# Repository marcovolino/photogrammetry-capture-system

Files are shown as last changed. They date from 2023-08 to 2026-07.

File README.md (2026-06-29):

# Photogrammetry Capture System

## Overview
This repository contains a set of documents that outline the developement of a 64-camera photogrammetry system for the capture of human subjects.

**Please see the [project website](https://marcovolino.github.io/photogrammetry-capture-system/) for full details.**

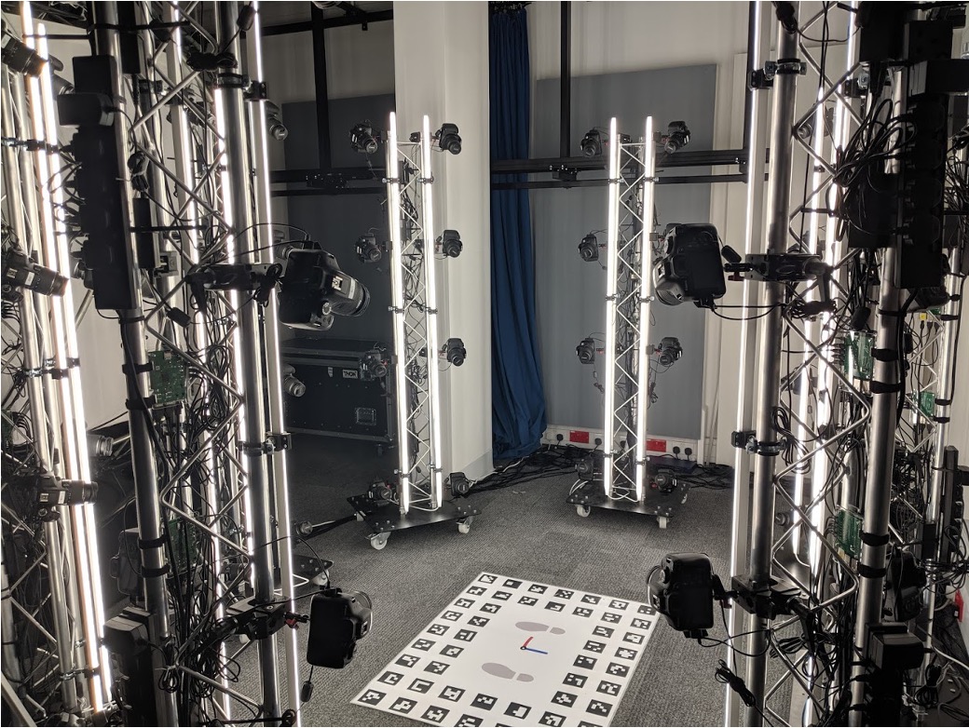
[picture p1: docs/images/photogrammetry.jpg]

<p style="text-align:center"><b>Figure 1:</b> Photogrammetry System</p>

If circumstances allow, the hardware design and software will be made open-source for others to recreate. For now, a description of the process can be found on the [project website](https://marcovolino.github.io/photogrammetry-capture-system/).

Any questions, [please get in touch](https://marcovolino.github.io/#contact).

## Updates
- 2023.08.11 - Repo/Site Created

## Documentation
- [System Overview](docs/system-overview.md)
- [Camera Synchronisation](docs/camera-sync.md)
- [Camera Control Software](docs/camera-control.md)
- [Control PC and Raspberry Pi Setup](docs/system-setup.md)
- [Floor Chart](docs/floor-chart.md)
- [Results](docs/results.md)

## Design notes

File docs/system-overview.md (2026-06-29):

---
layout: page
title: System Overview
---

This page gives a high-level overview of the capture system architecture.

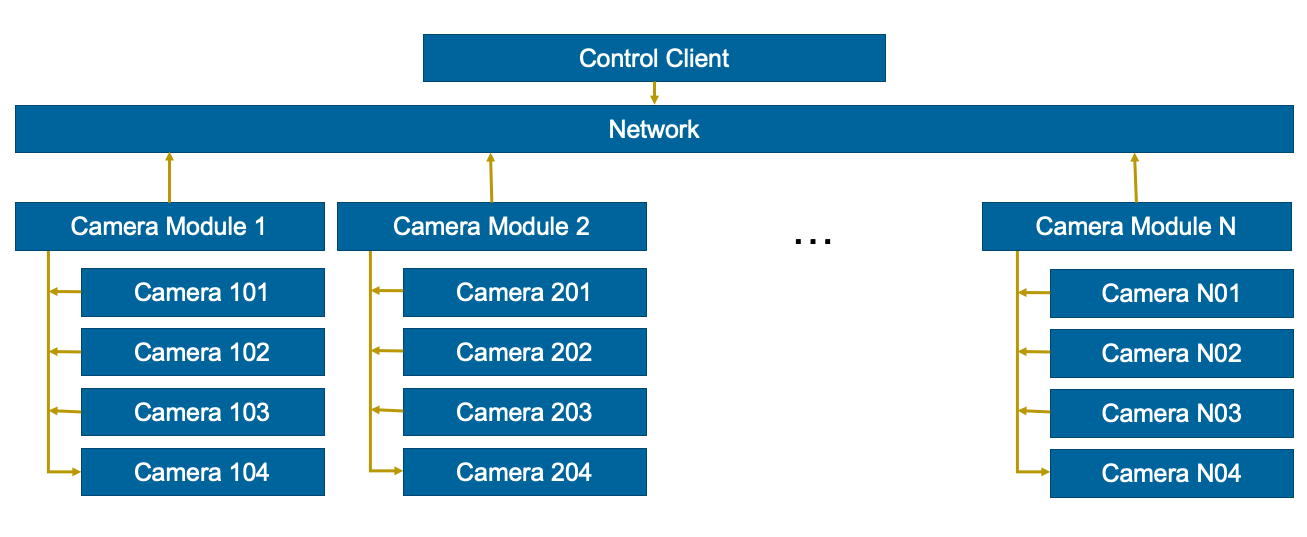
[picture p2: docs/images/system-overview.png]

<p style="text-align:center"><b>Figure 1:</b> System Overview</p>

The system consists of a central control PC and 16 camera modules connected over a local network. Each camera module is built around a [Raspberry Pi](https://www.raspberrypi.org/) and can support up to four DSLR cameras. Camera settings and image transfer are handled over USB, while autofocus and image capture is triggered through dedicated hardware so that all cameras fire at the same instant.

## Main Components

The control PC provides:

- A central operator interface for sending capture and configuration commands.
- A shared storage location for downloaded image data via FTP.
- A network time source so that Raspberry Pi modules can schedule captures from a common clock via NTP.

Each Raspberry Pi module provides:

- USB control for up to four DSLR cameras.
- A camera control server that listens for broadcast commands from the control PC.
- GPIO output for autofocus and shutter triggering through the custom trigger board.

Each DSLR camera provides:

- Image capture and local SD card storage.
- USB access for camera settings, card formatting, and image download.
- A 2.5 mm external trigger connection used by the synchronisation hardware.

## Capture Sequence

A typical capture follows this sequence:

1. The operator sends a command from the control PC.
2. The command is broadcast over UDP to the Raspberry Pi camera modules.
3. Each module schedules the capture using its local system clock.
4. At the trigger time, the module drives the GPIO trigger pin.
5. The custom trigger board closes the camera trigger circuit for each connected DSLR.
6. Captured images can then be downloaded from the cameras to the shared storage location.

The camera control software uses [libgphoto2](http://gphoto.org/) so that the control path is not tied to a single DSLR model, provided the camera is [supported by gphoto2](http://gphoto.org/proj/libgphoto2/support.php). The trigger hardware is camera-interface specific and was designed around DSLR bodies that expose focus and shutter control through a 2.5 mm remote trigger port.

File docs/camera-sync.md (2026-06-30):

---
layout: page
title:  Synchronisation
---

Photogrammetry systems designed to capture human subjects require precise shutter synchronisation so that all images represent the same instant. Even small timing differences can create reconstruction errors when the subject moves between frames.

This page describes the hardware-based synchronisation approach used by the system: a Raspberry Pi HAT that drives the external trigger inputs of multiple DSLR cameras.

## Camera Model

The [Canon EOS 1300D](https://www.canon.co.uk/for_home/product_finder/cameras/digital_slr/eos_1300d/) was selected because it offered a good balance of cost, resolution, external triggering support, and software control through libgphoto2.

The [camera control software](camera-control.md) is largely camera-model agnostic, provided the camera is supported by libgphoto2. The synchronisation hardware is more specific: it must match the camera's external trigger interface. Entry and mid-level Canon DSLR cameras commonly use a 2.5 mm jack for remote focus and shutter triggering.

## Software Trigger

Software triggering over USB was tested first. This approach was not precise enough for multi-camera human capture because it introduced variable delay between the first and last shutter event.

USB is still used for camera configuration and image transfer, but the capture signal is sent through the cameras' external trigger ports.

## Circuit Development and PCB Fabrication

The trigger board connects to the Raspberry Pi GPIO header and exposes multiple 2.5 mm trigger outputs for DSLR cameras. GPIO outputs from the Pi drive the trigger circuit, while opto-isolation helps separate the camera trigger lines from the Raspberry Pi electronics.

The following components were identified for building the circuit and sourced from <a target="_blank" href="https://uk.rs-online.com/web/">RS</a>.

<p style="text-align: center;"><b>Table 1: Component list with quantities per PCB and product links.</b></p>

| Component | Quantity per PCB | Link |
| --- | --- | --- |
| Diode (1N4148)	| 8 |<a target="_blank" href="https://uk.rs-online.com/web/p/switching-diodes/8431562">RS</a> |
| DIP Switch (SPST)| 1 |<a target="_blank" href="https://uk.rs-online.com/web/p/dip-sip-switches/8772154">RS</a> |
| GPIO Connector| 1| <a target="_blank" href="https://uk.rs-online.com/web/p/pcb-sockets/1731086">RS</a> |
| Headphone Jack (2.5mm) | 6 | <a target="_blank" href="https://uk.rs-online.com/web/p/products/5051407/">RS</a> |
| IC Dip Socket (8-way) | 1 |<a target="_blank" href="https://uk.rs-online.com/web/p/dil-sockets/6742435">RS</a>|
| Opto Isolator (CNY74-2)	| 1 | <a target="_blank" href="https://uk.rs-online.com/web/p/optocouplers/1451599/">RS</a>|
| Resistor (1k) | 2 |<a target="_blank" href="https://uk.rs-online.com/web/p/through-hole-resistors/7077666">RS</a>|

The circuit design was reproduced in <a target="_blank" href="https://www.kicad.org/">KiCad</a>, an open-source PCB design package.
KiCad was used to lay out the Raspberry Pi HAT form factor and route the trigger circuit. Some component footprints were not available in the default libraries, so custom footprints were created from the component datasheets.

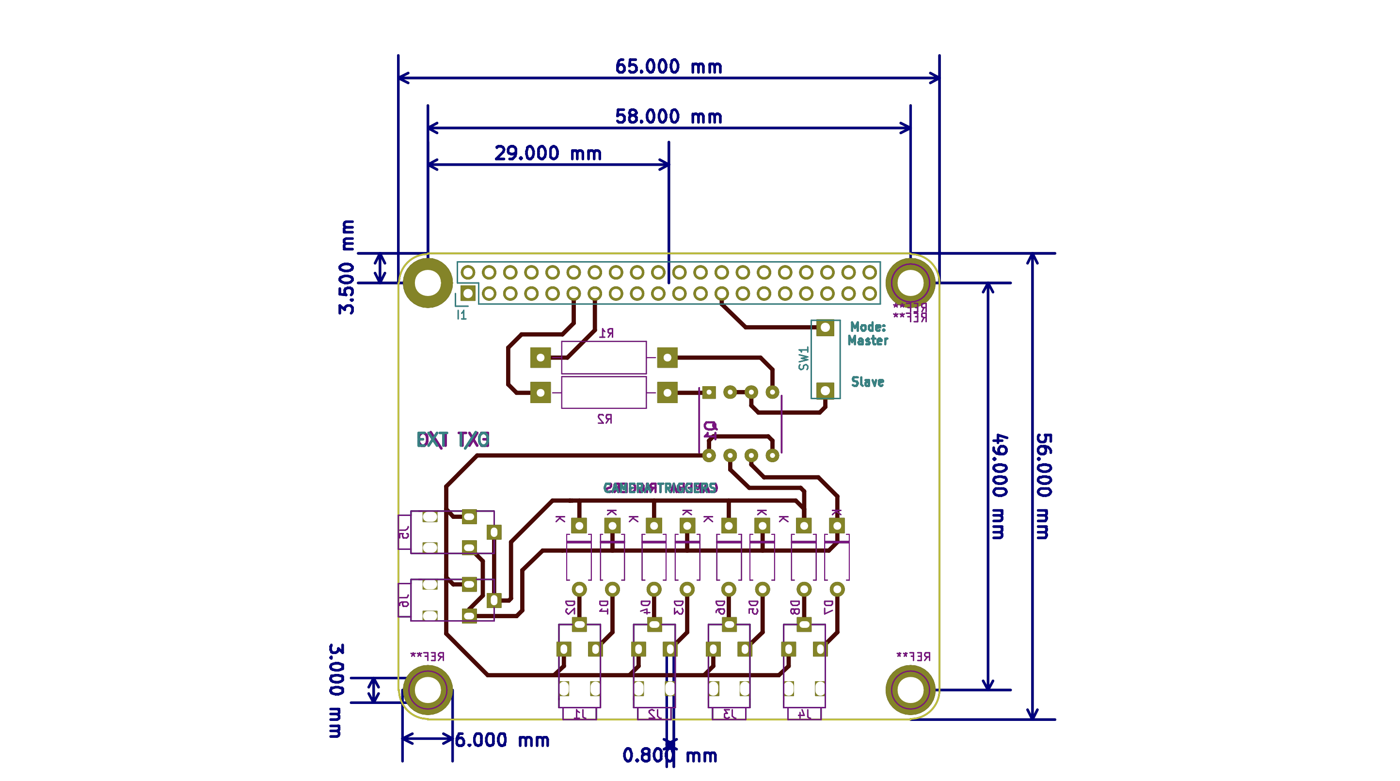
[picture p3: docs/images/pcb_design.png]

<p style="text-align: center;"><b>Figure 1:</b> PCB layout for the Raspberry Pi HAT trigger board.</p>

A prototype of the design was fabricated with the help of the University of Surrey's Electronics Lab, who used a UV etching process to create a PCB.
After confirming that the prototype circuit operated as expected, I began the process of fabricating 16 of the boards for the full system. 

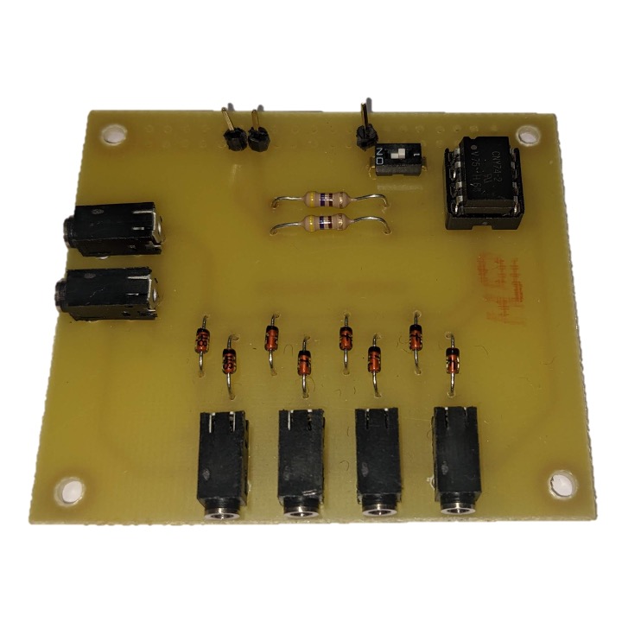
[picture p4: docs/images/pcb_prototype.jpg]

<p style="text-align: center;"><b>Figure 2:</b> Prototype PCB fabricated by the University of Surrey Electronics Lab using UV etching.</p>

The prototype fabrication process involved manually drilling component holes, which was not considered to be precise enough to ensure a high quality set of PCBs. 
For this reason, the manufacture of the final PCB boards was outsourced to a third party company.

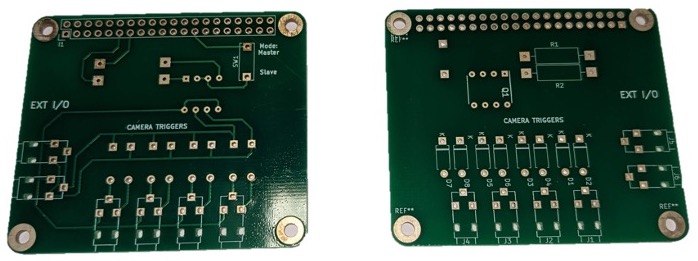
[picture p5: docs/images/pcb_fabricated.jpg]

<p style="text-align: center;"><b>Figure 3:</b> Fabricated PCB.</p>

Each PCB was then soldered together in the University of Surrey's Electronics Lab using the components listed previously.

## Synchronisation Tests

The synchronisation test captures the same moving event from multiple camera modules. If the trigger path is working correctly, the corresponding frames should show the event at the same point in time across cameras.
In figure 4, below, we see a croped image of an in-house synchronisation checker from 8 of the 16 camera modules. This demonstrates a high level of shutter synchronisation between independent cameras modules meaning a precise level of synchronisation, below 1/100th of a second, this is suitable for static human capture. 

This test is useful because it exercises the complete timing path:

- Network command broadcast from the control PC.
- Clock synchronisation between modules.
- Scheduled trigger timing on each Raspberry Pi.
- GPIO output through the trigger board.
- Camera response through the external trigger port.

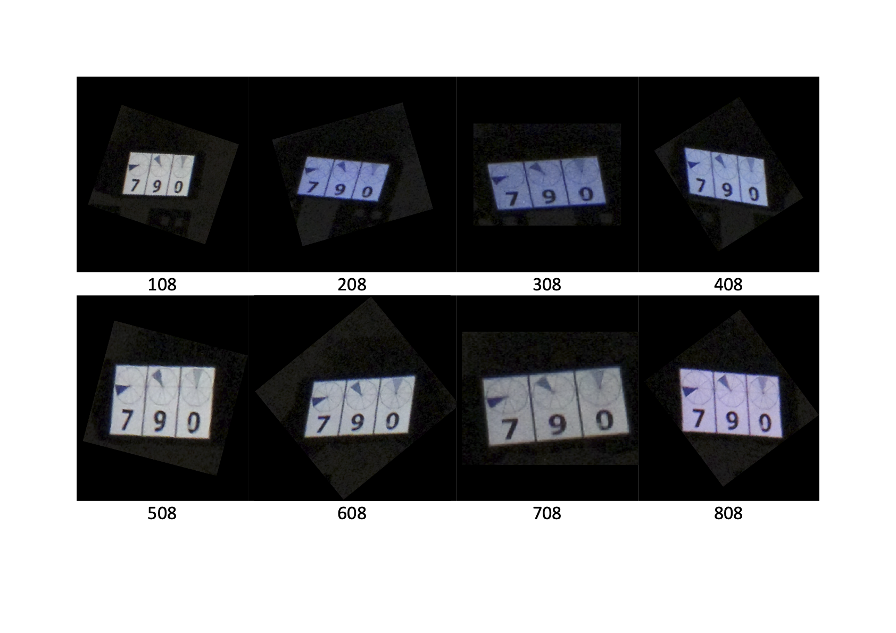
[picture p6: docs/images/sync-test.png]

<p style="text-align: center;"><b>Figure 4:</b> Images captured from different camera modules during a synchronisation test.</p>

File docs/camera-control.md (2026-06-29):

---
layout: page
title: Camera Control
---

The camera control software coordinates the central control PC and the Raspberry Pi camera modules. It provides a lightweight command interface for changing camera settings, triggering captures, downloading images, and managing camera modules.

The implementation is written in C++ and uses:

- [Boost.Asio](https://www.boost.org/doc/libs/release/doc/html/boost_asio.html) for UDP networking.
- [libgphoto2](http://gphoto.org/) for DSLR camera discovery, configuration, capture, download, and file deletion.
- [wiringPi](http://wiringpi.com/) for Raspberry Pi GPIO access.

## Architecture

The software is split into two applications:

- `CameraControlClient` runs on the control PC.
- `CameraControlServer` runs on each Raspberry Pi camera module.

The client sends commands to the modules using UDP broadcast. This keeps the control path simple: every active module receives the same command at the same time, and each module applies it to the cameras connected locally.

## Client Application

The client is an interactive command-line tool. It reads a JSON configuration file containing the broadcast address, UDP port, download directory, and optional host list for hard shutdown or reboot commands.

Example configuration:

```json
{
  "broadcast-address": "192.168.0.255",
  "port": 2000,
  "download": "/net_home/data",
  "pssh-hosts": "192.168.0.101 192.168.0.102"
}
```

The client maps single-key input to camera commands. Some commands prompt for a value, such as ISO, aperture, or shutter speed. Capture commands generate a future timestamp, allowing each camera module to trigger from its synchronized local clock.

## Server Application

The server listens for UDP commands on the configured port. When a command is received, it is parsed as either:

- `command`
- `command:value`

The server then applies the command to the local camera controller. Supported operations include:

- Detect connected cameras.
- Set ISO, aperture, and shutter speed.
- Trigger capture using GPIO.
- Enable or disable autofocus through GPIO.
- Download images to the configured destination.
- Format camera SD cards by deleting stored files.
- Shutdown or reboot the Raspberry Pi.

## Camera Discovery and Control

Each Raspberry Pi module uses libgphoto2 to detect cameras connected over USB. Detected cameras are opened, configured to store captures on their memory cards, and wrapped by the local camera controller.

Camera settings are applied using gphoto2 configuration keys:

- `iso`
- `aperture`
- `shutterspeed`

The software currently exposes a fixed set of accepted values for ISO, aperture, and shutter speed. These values should match the options supported by the selected camera model.

## Hardware Triggering

Although libgphoto2 can trigger image capture over USB, this was not accurate enough for synchronised multi-camera capture. The production capture path uses GPIO instead:

- One GPIO pin controls autofocus.
- One GPIO pin controls shutter trigger.
- The custom Raspberry Pi trigger board converts the GPIO output into the external trigger signal expected by the cameras.

This keeps camera setting and data transfer on USB, while using the dedicated camera trigger interface for precise capture timing. See [Camera Synchronisation](/camera-sync) for more details

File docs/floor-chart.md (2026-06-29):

---
layout: page
title: Floor Chart
---

The reconstruction pipeline estimates camera and subject geometry in an arbitrary coordinate system, usually with the origin attached to one of the solved cameras. It also reconstructs at an arbitrary scale. A floor chart provides known geometry in the capture volume so the final model can be aligned, oriented, and scaled in metric units.

The chart is based on the <a href="https://docs.opencv.org/4.x/d5/dae/tutorial_aruco_detection.html" target="_blank">ArUco</a> library that ships as part of <a href="https://opencv.org/" target="_blank">OpenCV</a>.

## Board Generation

```
example_aruco_create_board 
```

The following parameters control the creation of the board:

- d - dictionary: DICT\_4X4\_50=0, DICT\_4X4\_100=1, etc...
- w - Number of squares in X direction
- h - Number of squares in Y direction
- l - Marker side length (in pixels)
- s - Separation between two consecutive markers in the grid (in pixels)
- m - Margins size (in pixels)

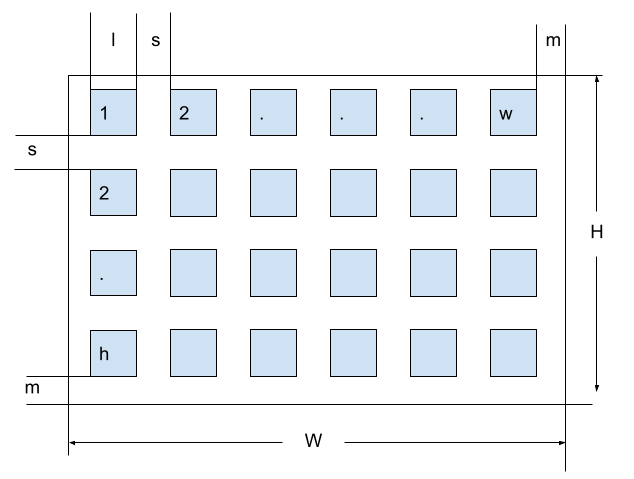
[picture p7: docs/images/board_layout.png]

<p style="text-align: center;"><b>Figure 1:</b> ArUco board layout.</p>

Given the parameters that control the drawing of the board and known structure, it is possible to formulate the width and height of the board in pixels as follows:

```math
W=2m+wl+(w-1)s
```
```math
H=2m+hl+(h-1)s
```

Making $s$ proportional to the size $l$ using variable $x$

```math
W=2m+wl+(w-1)xl
```
```math
H=2m+hl+(h-1)xl
```

Setting $W$ and $H$ to the size of A0 in pixels at 300 dpi removing the margin

```math
W_p = 1.189/0.0254*300 = 14043
```
```math
H_p = 0.841/0.0254*300 = 9933
```

```math
14043=wl+(w-1)xl
```
```math
9933=hl+(h-1)xl
```

The computed parameters can therefore be used to generate an A0 sized ArUco board at 300 DPI suitable for high-quality printing.  

```
./example_aruco_create_board -d=1 -w=9 -h=7 -m=0 -l=900 -s=585 floor-chart_7x5_a0.png
```

The generated image was then edited to remove the central portion of markers and replace it with footprints and arrows representing the X-Z plane. This gives the subject a clear standing position while preserving known fiducial markers around the capture area.

The image below shows the final floor chart after editing.

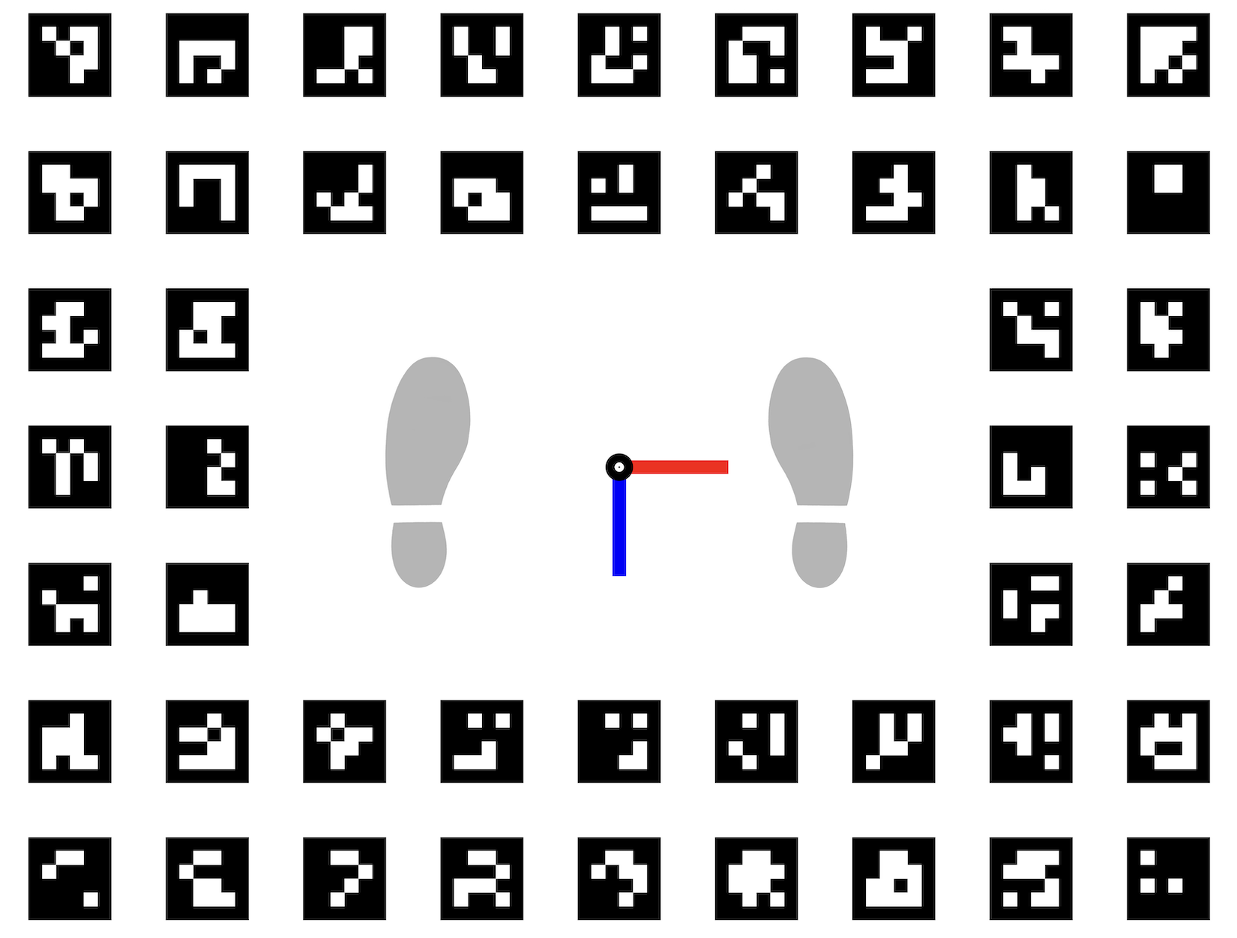
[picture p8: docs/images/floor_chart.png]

<p style="text-align: center;"><b>Figure 2:</b> Final floor chart.</p>

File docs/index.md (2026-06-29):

---
layout: page
title: Photogrammetry Capture System
---

This site documents a 64-camera photogrammetry capture system built at the University of Surrey's [Centre for Vision, Speech and Signal Processing](https://www.surrey.ac.uk/cvssp) by [Marco Volino](https://marcovolino.github.io/).

The system was designed to capture human subjects from many viewpoints at the same instant. It combines a central control PC, Raspberry Pi camera modules, DSLR cameras, a custom hardware trigger board, and a floor calibration chart for recovering metric scale and orientation.

photogrammetry system
<p style="text-align:center"><b>Figure 1:</b> Photogrammetry System</p>

## Documentation
The site is organised across the following topics, which are accessible across the menu bar at the top of the page:

1. [System Overview](system-overview.md)
2. [Camera Synchronisation](camera-sync.md)
3. [DSLR Camera Control](camera-control.md)
4. [Client and Raspberry Pi Setup](system-setup.md)
5. [Floor Chart](floor-chart.md)
6. [Results](results.md)

The camera control source code and PCB support files used while designing the Raspberry Pi trigger hardware will be released at some point in the future to help democratise these systems.

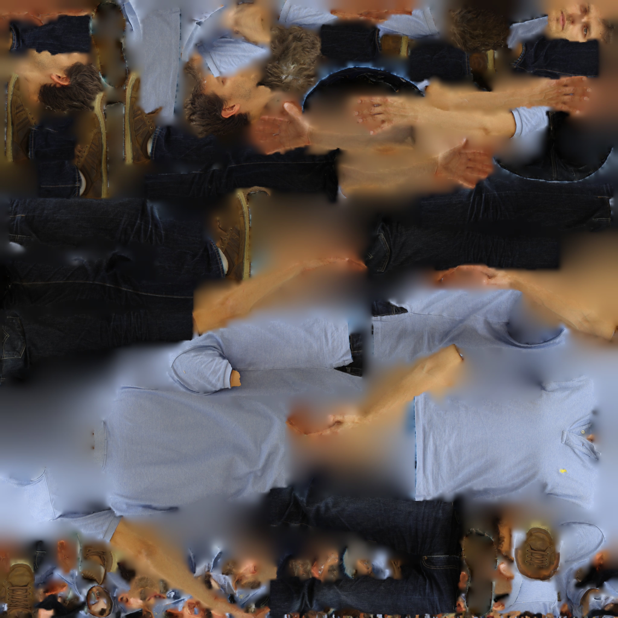
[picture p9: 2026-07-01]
docs/assets/model/model_4k.jpg

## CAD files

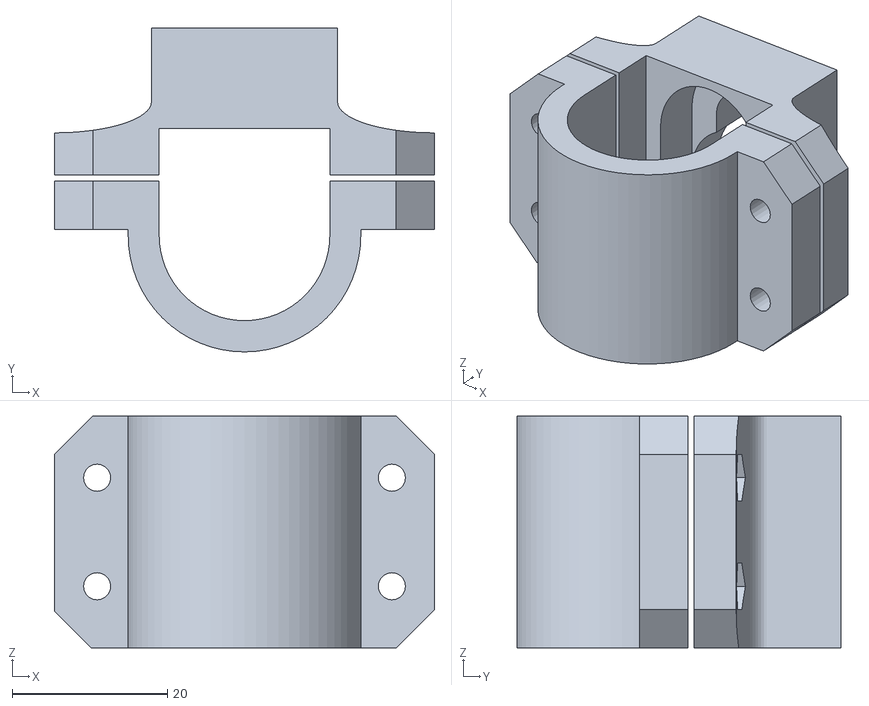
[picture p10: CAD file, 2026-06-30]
light_bracket/light_bracket.obj
49.0 x 41.8 x 29.9

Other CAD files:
rpi_perspex_case/rpi_perspex_case.dwg

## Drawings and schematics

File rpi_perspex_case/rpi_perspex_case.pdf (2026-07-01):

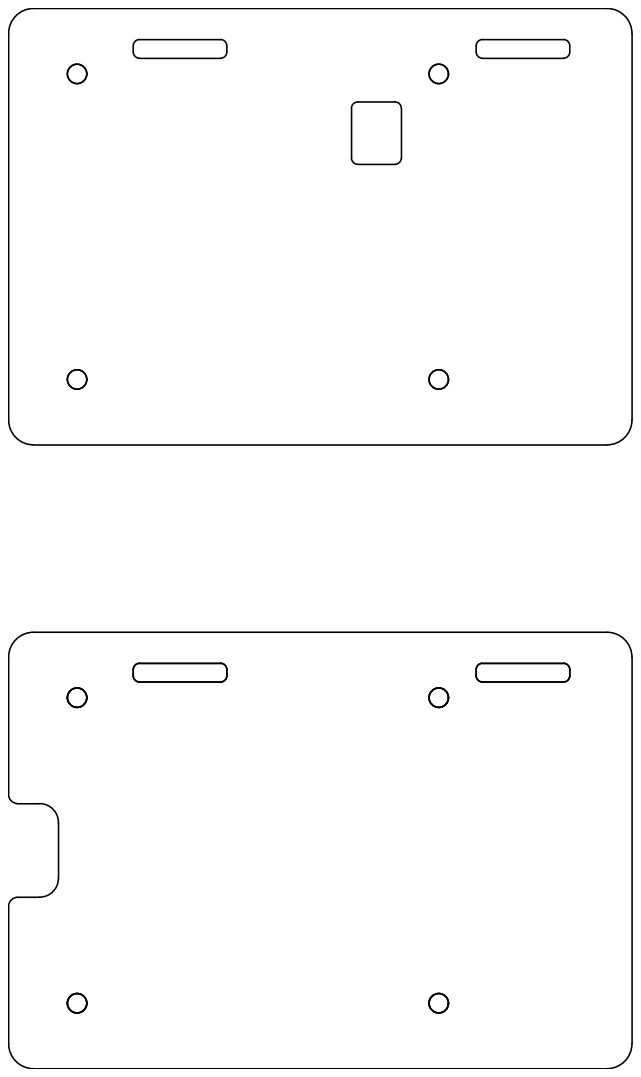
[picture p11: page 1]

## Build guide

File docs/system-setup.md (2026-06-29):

---
layout: page
title: System Setup
---

This page describes the main setup responsibilities for the control PC, Raspberry Pi camera modules, cameras, network, and capture area.

photogrammetry system
<p style="text-align:center"><b>Figure 1:</b> Photogrammetry System</p>

## Physical Layout

The system is arranged around a central capture volume for a standing human subject. Cameras are mounted on towers around the subject so that the final image set contains views from different heights and angles.

The full system uses 16 Raspberry Pi camera modules. Each module can control up to four DSLR cameras, giving a maximum of 64 cameras. The system is modular and scalable and can support hundreds or even thousands of cameras. 

The capture volume should include:

- A clear subject position.
- Even lighting across the face, body, and clothing.
- Camera towers positioned to reduce occlusion.
- Cable routing that keeps USB, trigger, power, and network cables secure.
- The printed floor chart placed where it can be seen by enough cameras for scale and orientation recovery- see [Floor Chart ](/floor-chart) for more details.

## Control PC

The control PC is responsible for operating the capture system. It should provide:

- The camera control client application.
- A network connection to every Raspberry Pi module.
- A shared destination for downloaded images.
- A network time service so modules can maintain synchronized clocks.

The camera control configuration defines the broadcast address, UDP port, download directory, and optional Raspberry Pi host list used for hard reboot or shutdown operations.

## Raspberry Pi Modules

Each Raspberry Pi module should provide:

- USB connections to its local cameras.
- The camera control server application.
- The custom trigger board connected to the GPIO header.
- Network access to the control PC.
- System clock synchronization against the control PC or another local time source.

On startup, the server detects connected cameras through libgphoto2 and prepares the GPIO pins used for autofocus and shutter triggering.

## Cameras

Each DSLR camera should be configured consistently before capture:

- Manual exposure settings.
- Controlled autofocus behaviour.
- External trigger cable connected to the trigger board.
- USB connected to the Raspberry Pi module.
- SD card inserted and ready for storage.
- Set Owner Data meta data per camera to identify each device

The control software can set ISO, aperture, and shutter speed where those settings are supported by libgphoto2 for the camera model.

## Network

The camera modules and control PC communicate over a local network. The client sends UDP broadcast commands to all modules using the configured broadcast address and port.

For reliable operation:

- Keep all modules on the same subnet as the control PC.
- Confirm that UDP broadcast traffic is allowed on the selected network.
- Assign fixed Raspberry Pi addresses if hard shutdown or reboot commands are needed.
- Verify time synchronization before scheduled capture tests.

## Capture Checklist

Before a capture session:

1. Power on the control PC, network switch, Raspberry Pi modules, cameras, and lights.
2. Confirm that all modules are reachable on the network.
3. Start the camera control server on each Raspberry Pi module.
4. Start the camera control client on the control PC.
5. Detect cameras and confirm the expected number is reported.
6. Set exposure parameters.
7. Test autofocus and trigger behaviour.
8. Capture a small test set and download images.
9. Check image naming, exposure, sharpness, and coverage before full capture.

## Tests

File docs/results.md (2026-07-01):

---
layout: page
title: Results
---

<link rel="stylesheet" href="{{ '/assets/css/model-viewer.css' | relative_url }}">
<script type="module" src="{{ '/assets/js/result-viewer.js' | relative_url }}"></script>

This page highlights example outputs and validation images from the capture system. The results shown here focus on the captured images and the reconstruction quality.

## Reconstruction 

The captured images have been processed using RealityCapture 2.2 and are shown below.

The viewer below shows a textured OBJ result generated from the capture system. Drag to orbit the model, scroll or pinch to zoom, and tap or double-click the scan to focus the camera on that point. The viewer starts with the 4K texture for faster loading, with the 8K texture available from the resolution selector.

<div class="result-viewer" data-result-viewer>
  <div class="result-viewer__frame">
    <canvas class="result-viewer__canvas" aria-label="Interactive 3D preview of a photogrammetry reconstruction"></canvas>
    
  </div>
  <div class="result-viewer__toolbar">
    <div class="result-viewer__groups">
      <div class="result-viewer__button-group" role="group" aria-label="Viewing mode">
        <button class="result-viewer__button result-viewer__button--active" type="button" data-view-mode="texture" aria-pressed="true">Unlit texture</button>
        <button class="result-viewer__button" type="button" data-view-mode="shaded" aria-pressed="false">Shaded geometry</button>
        <button class="result-viewer__button" type="button" data-view-mode="wireframe" aria-pressed="false">Wireframe</button>
      </div>
      <div class="result-viewer__button-group" role="group" aria-label="Texture resolution">
        <button class="result-viewer__button result-viewer__button--active" type="button" data-texture-resolution="4k" aria-pressed="true">4K texture</button>
        <button class="result-viewer__button" type="button" data-texture-resolution="8k" aria-pressed="false">8K texture</button>
      </div>
    </div>
    <div class="result-viewer__button-group result-viewer__button-group--actions" role="group" aria-label="Viewer actions">
      <button class="result-viewer__button" type="button" data-fullscreen-view aria-pressed="false">Fullscreen</button>
      <button class="result-viewer__button" type="button" data-reset-view>Reset view</button>
    </div>
  </div>
</div>

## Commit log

2023-08-11 switch images to use md
2023-08-16 more detail added to camera sync
2023-08-16 more details added to camera sync
2023-08-16 added datasheets, kicad modules and libraries
2026-06-29 Update documentation and system configuration
    - Refactor index page to provide a clearer introduction to the photogrammetry capture system.
    - Enhance camera control documentation with detailed software architecture and usage instructions.
    - Improve camera synchronization page to clarify the hardware-based solution for shutter synchronization.
    - Revise floor chart documentation for better clarity on its purpose and usage in the capture process.
    - Add results page to showcase example outputs and validation images from the capture system.
    - Update system overview to include detailed descriptions of components and capture sequence.
    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
2026-06-30 Update title in camera sync documentation for consistency
2026-06-30 Added lightbracket 3d model
    [light_bracket.obj]
2026-06-30 Add floor chart calculations spreadsheet
    [floor_chart_calculations.ods]
2026-07-01 added autocad drawing and file for raspberry pi perspex case
    [rpi_perspex_case.dwg]
2026-07-01 added full screen rendering mode and buttons to select between texture sizes.
